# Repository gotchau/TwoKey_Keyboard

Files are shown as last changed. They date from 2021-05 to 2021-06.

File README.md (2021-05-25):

# TwoKey_Keyboard
## Внешний вид клавиатуры
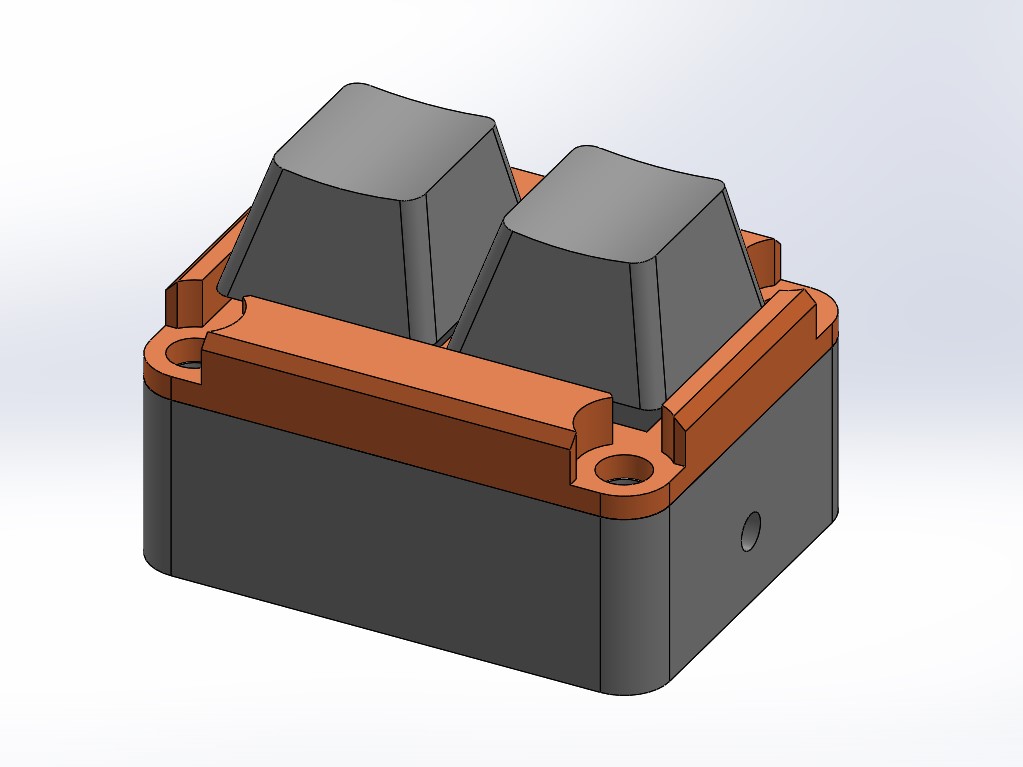
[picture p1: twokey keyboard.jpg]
Image alt


## Видео
Видео (https://youtu.be/BGkTiVP5ryY "Видео")

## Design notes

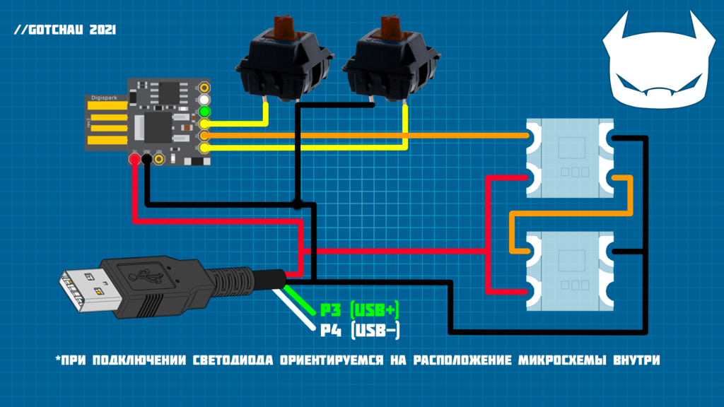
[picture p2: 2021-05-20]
схема.png

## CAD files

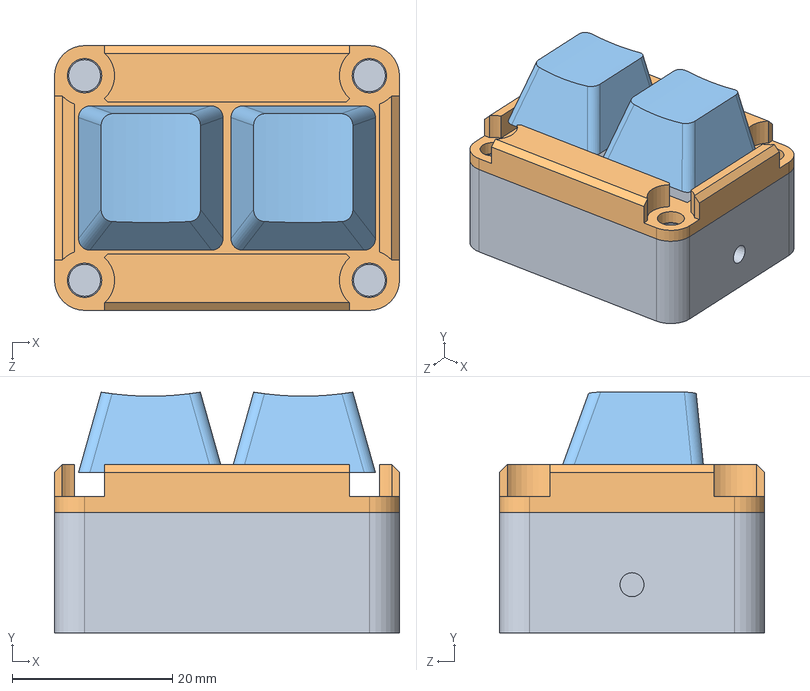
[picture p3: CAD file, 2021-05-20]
GTK Keyboard Models/Source/Gotchau TwoKeyKeyboard.SLDASM
43.0 x 30.0 x 33.0 mm
twoKeyBase
twoKeyTop
keyCap x 2

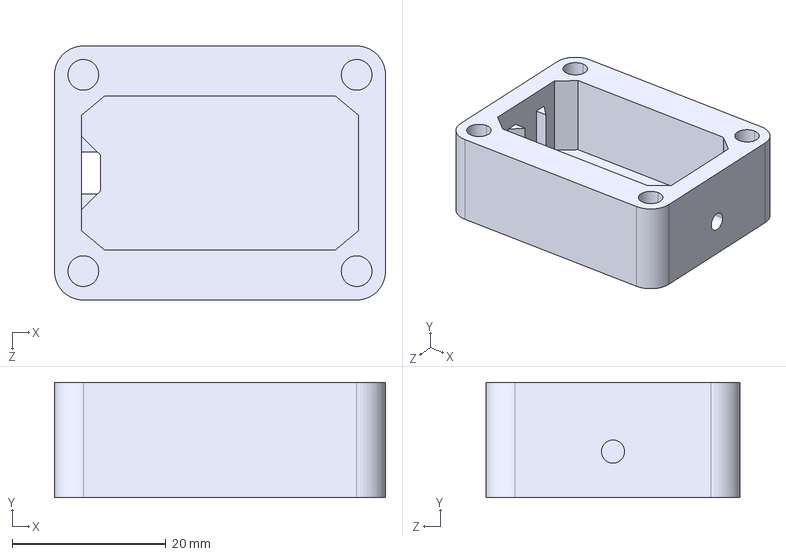
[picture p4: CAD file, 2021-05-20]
GTK Keyboard Models/STEP/twoKeyBase.STEP
43.0 x 15.0 x 33.0 mm

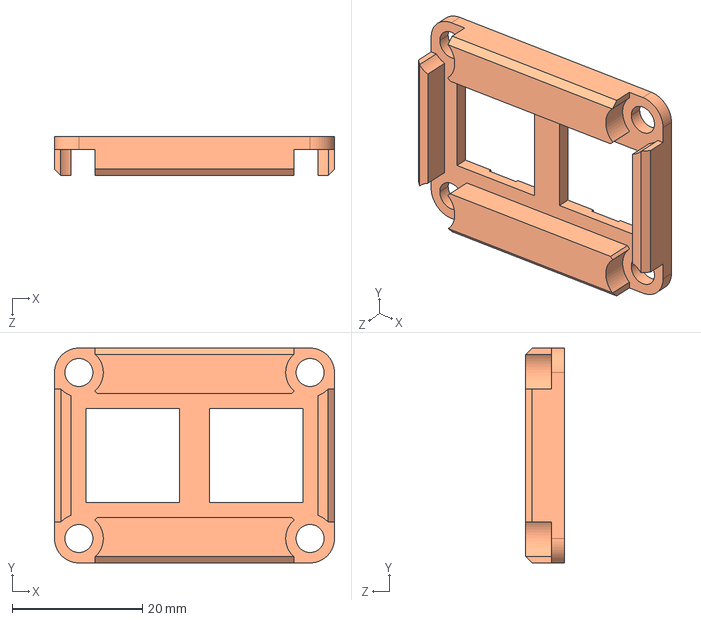
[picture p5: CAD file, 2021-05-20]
GTK Keyboard Models/STEP/twoKeyTop.STEP
43.0 x 33.0 x 6.00 mm

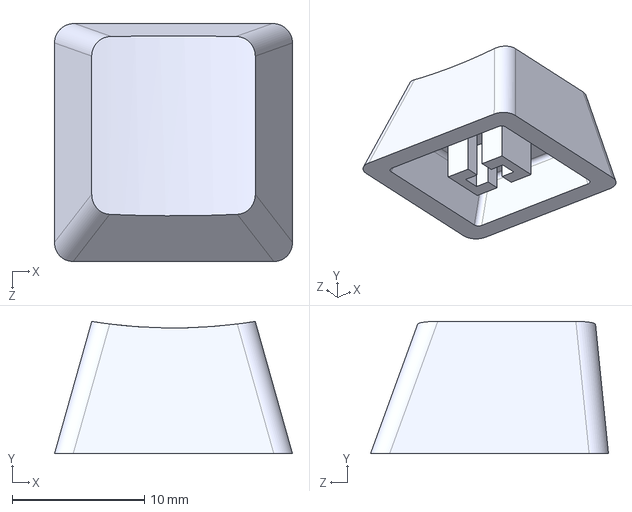
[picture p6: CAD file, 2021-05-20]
GTK Keyboard Models/STEP/keyCap.STEP
18.0 x 10.0 x 18.0 mm

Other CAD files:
GTK Keyboard Models/STEP/keyCapSimp.STEP
GTK Keyboard Models/STL/keyCap.STL
GTK Keyboard Models/STL/keyCapSimp.STL
GTK Keyboard Models/STL/twoKeyBase.STL
GTK Keyboard Models/STL/twoKeyTop.STL
GTK Keyboard Models/Source/keyCap.SLDPRT
GTK Keyboard Models/Source/keyCapSimp.SLDPRT
GTK Keyboard Models/Source/twoKeyBase.SLDPRT
GTK Keyboard Models/Source/twoKeyTop.sldprt

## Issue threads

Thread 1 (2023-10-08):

Проблема с прошивкой или с платой, насущные вопросы.

c7v, 2023-10-08:
Собрать было не трудно, трудно понять прошивка норм работает или нет? Получилось так, что я собираю без светодиодов, пришлось прошивку немного отредактировать, получилось это:

```c#
#include <TrinketHidCombo.h>

#define USB_CFG_VENDOR_NAME 'G', 'o', 't', 'c', 'h', 'a', 'u'
#define USB_CFG_VENDOR_NAME_LEN 7
#define USB_CFG_DEVICE_NAME 'G', 'o', 't', 'c', 'h', 'a', 'u' ' ', 'H', 'I', 'D',
#define USB_CFG_DEVICE_NAME_LEN 11

#define PIN_BTN_A 0
#define PIN_BTN_B 2

void setup()
{
  pinMode(PIN_BTN_A, INPUT_PULLUP);
  pinMode(PIN_BTN_B, INPUT_PULLUP);

  TrinketHidCombo.begin();
}

void loop()
{
  uint32_t now = millis();

  if (!digitalRead(PIN_BTN_A))
  {
    TrinketHidCombo.pressMultimediaKey(MMKEY_VOL_UP);
  }

  if (!digitalRead(PIN_BTN_B))
  {
    TrinketHidCombo.pressMultimediaKey(MMKEY_VOL_DOWN);
  }

  TrinketHidCombo.poll();
}

```

Судя по Arduino IDE прошивка зашла как родная. Однако после перезагрузки устройства, в диспетчере устройств я не вижу появление или пропажу какого-то USB устройства. После перепрошивки, как ПК должен определять это устройство?

Другой вопрос, не хочу возиться с паяльником до тех пор, пока не пойму, правильно ли встала прошивка. Как мне протестировать работу без припайки свечей, может замкнуть какие-то выходы на плате?

После перепрошивки моргает красный светодиод, это так и должно быть? До перепрошивки он не моргал.

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

c7v, 2023-10-08:
Дополнительно:
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

c7v, 2023-10-08:
Решение найдено, смотрите #2

Closed 2023-10-08.

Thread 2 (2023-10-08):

Проблема USB

c7v, 2023-10-08:
В видео припаян белый провод USB- и в USB+ правильно, но потом сообщается что нужно поменять местами, то несть на плате где USB- нам нужно зелёный провод который является USB+ и на оборот со вторым, к USB+ на плате пояем USB-.

Если припоять провода правильно, то устройство не обнаруживается, но если поменять местами, то:

Да, при таком раскладе у меня были попытки прошить контроллер, ARDUINO IDE хотя бы начала выводить процент загрузки, однако вина постоянно то находила устройство, то теряло его.

c7v, 2023-10-08:
Проблема #1 может быть связана с этим нюансом.

c7v, 2023-10-08:
Чудо! Установил Arduino 1.8.18 все начало перепрошиваться, при этом чудо в том, что USB Data - и + сделал перепутанными как в видео.

Closed 2023-10-08.

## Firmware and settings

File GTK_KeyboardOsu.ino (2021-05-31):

// Osu edition! 31/05/2021
// Скечт для двухкнопочной клавиатуры с RGB-подсветкой на ws2812 2020.
// Библиотеки Adafruit занимают много места, потом поменяю.
// Примечание. Оба режима прекрасно работают с версией библиотеки Adafruit NeoPixel@1.3.4
//
// Ссылки на библиотеки:
// TrinketHidCombo https://github.com/adafruit/Adafruit-Trinket-USB/tree/master/TrinketHidCombo
// Adafruit_NeoPixel https://github.com/adafruit/Adafruit_NeoPixel
// YouTube https://youtu.be/BGkTiVP5ryY
// Gotchau 06/02/2021

#include <Arduino.h>
#include <TrinketHidCombo.h>
#include <Adafruit_NeoPixel.h>

#define USB_CFG_VENDOR_NAME 'G', 'o', 't', 'c', 'h', 'a', 'u'
#define USB_CFG_VENDOR_NAME_LEN 7
#define USB_CFG_DEVICE_NAME 'G', 'o', 't', 'c', 'h', 'a', 'u' ' ', 'H', 'I', 'D',
#define USB_CFG_DEVICE_NAME_LEN 11

#define PIN_BTN_A 0
#define PIN_BTN_B 2

#define PIN_LEDS 1
#define NUMPIXELS 2
Adafruit_NeoPixel pixels(NUMPIXELS, PIN_LEDS, NEO_GRB + NEO_KHZ800);

uint32_t lastTime = 0;
uint8_t periodMs = 10; // отвечает за скорость анимации. Меньше - быстрее.

uint8_t btnBrightness[] = {100, 100};

bool leftBtnState = 0;
bool leftBtnLastState = 0;

bool rightBtnState = 0;
bool rightBtnLastState = 0;

void setup()
{
  pinMode(PIN_BTN_A, INPUT_PULLUP);
  pinMode(PIN_BTN_B, INPUT_PULLUP);

  TrinketHidCombo.begin();
  pixels.begin();
  pixels.setBrightness(255);
}

void fading()
{
  for (int i = 0; i < 2; i++)
    if (btnBrightness[i] > 0)
    {
      uint32_t color = pixels.getPixelColor(i);
      uint8_t r = ((color & 0x00FF0000) >> 16) * btnBrightness[i] / 100;
      uint8_t g = ((color & 0x0000FF00) >> 8) * btnBrightness[i] / 100;
      uint8_t b = (color & 0x000000FF) * btnBrightness[i] / 100;

      pixels.setPixelColor(i, pixels.Color(r, g, b));
      btnBrightness[i]--;
      pixels.show();
    }
}

void rainbow2(uint16_t step)
{
  static long firstPixelHue = 0;
  firstPixelHue += step;

  if (firstPixelHue > 5 * 65536)
    firstPixelHue = 0;

  for (uint16_t i = 0; i < pixels.numPixels(); i++)
  {
    int pixelHue = firstPixelHue + (i * 65536L / pixels.numPixels());
    pixels.setPixelColor(i, pixels.gamma32(pixels.ColorHSV(pixelHue)));
  }
  pixels.show();
}

void loop()
{
  uint32_t now = millis();
  if (now - lastTime > periodMs)
  {
    lastTime = now;

    //Плавное затухание
    //fading();
    //Режим тру-геймера. Аргументом передается плавность радуги. Меньше-плавнее.
    rainbow2(127);
  }

  //считываем текущее значение
  leftBtnState = !digitalRead(PIN_BTN_A);
  // при нажатии левой кнопки
  if (leftBtnState && !leftBtnLastState)
  {
    leftBtnLastState = leftBtnState;
    TrinketHidCombo.pressKey(0, KEYCODE_Z);
    pixels.setPixelColor(0, pixels.Color(150, 0, 210)); // любой цвет в формате RGB 0-255
    btnBrightness[0] = 100;
  }
  // при отпускании левой кнопки
  if (!leftBtnState && leftBtnLastState)
  {
    leftBtnLastState = leftBtnState;
    TrinketHidCombo.pressKey(0, 0);
  }

  //считываем текущее значение
  rightBtnState = !digitalRead(PIN_BTN_B);
  // при нажатии правой кнопки
  if (rightBtnState && !rightBtnLastState)
  {
    rightBtnLastState = rightBtnState;
    TrinketHidCombo.pressKey(0, KEYCODE_X);
    pixels.setPixelColor(1, pixels.Color(150, 0, 210)); // любой цвет в формате RGB 0-255
    btnBrightness[1] = 100;
  }
  // при отпускании правой кнопки
  if (!rightBtnState && rightBtnLastState)
  {
    rightBtnLastState = rightBtnState;
    TrinketHidCombo.pressKey(0, 0);
  }

  TrinketHidCombo.poll();
}

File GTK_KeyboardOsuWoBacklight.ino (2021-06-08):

// Osu edition! без подсветки 08/06/2021
// Скечт для двухкнопочной клавиатуры.
// Библиотеки Adafruit занимают много места, потом поменяю.
//
// Ссылки на библиотеки:
// TrinketHidCombo https://github.com/adafruit/Adafruit-Trinket-USB/tree/master/TrinketHidCombo
// YouTube https://youtu.be/BGkTiVP5ryY
// Gotchau 06/02/2021

#include <Arduino.h>
#include <TrinketHidCombo.h>

#define PIN_BTN_A 0
#define PIN_BTN_B 2

bool leftBtnState = 0;
bool leftBtnLastState = 0;
uint32_t leftBtnLastTimePressed = 0;

bool rightBtnState = 0;
bool rightBtnLastState = 0;
uint32_t rightBtnLastTimePressed = 0;

void setup()
{
  pinMode(PIN_BTN_A, INPUT_PULLUP);
  pinMode(PIN_BTN_B, INPUT_PULLUP);

  TrinketHidCombo.begin();
}

void loop()
{
  uint32_t now = micros();

  //считываем текущее значение
  leftBtnState = !digitalRead(PIN_BTN_A);
  if (now - leftBtnLastTimePressed > 1000)
  {
    leftBtnLastTimePressed = now;

    // при нажатии левой кнопки
    if (leftBtnState && !leftBtnLastState)
    {
      leftBtnLastState = leftBtnState;
      TrinketHidCombo.pressKey(0, KEYCODE_Z);
    }
    // при отпускании левой кнопки
    if (!leftBtnState && leftBtnLastState)
    {
      leftBtnLastState = leftBtnState;
      TrinketHidCombo.pressKey(0, 0);
    }
  }

  //считываем текущее значение
  rightBtnState = !digitalRead(PIN_BTN_B);
  if (now - rightBtnLastTimePressed > 1000)
  {
    rightBtnLastTimePressed = now;

    // при нажатии правой кнопки
    if (rightBtnState && !rightBtnLastState)
    {
      rightBtnLastState = rightBtnState;
      TrinketHidCombo.pressKey(0, KEYCODE_X);
    }
    // при отпускании правой кнопки
    if (!rightBtnState && rightBtnLastState)
    {
      rightBtnLastState = rightBtnState;
      TrinketHidCombo.pressKey(0, 0);
    }
  }

  TrinketHidCombo.poll();
}
